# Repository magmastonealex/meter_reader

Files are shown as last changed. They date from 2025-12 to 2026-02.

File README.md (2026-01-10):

meter_reader
====

This is an open-hardware design for a magnetic gas / water meter "reader" or "snooper". It contains a magnetometer and microcontroller, and can measure the rotations of a water meter or oscillations of the bellows in a gas meter to fairly accurately track consumption of both natural gas and water.

The device communicates externally using CAN, accepting configuration and reporting sensor values.

Schematics and PCB design are in the root of this repository. I have built a few devices, but would not consider the hardware to be "fully qualified" yet - I still need to do some transient testing and measure power supplies and signal integrity. I'd also still like to find a more available magnetometer - MLX3094RLD is _barely_ available and a bit annoying to solder.

Firmware in `firmware/` is Rust code targetting the MSPM0G3107 on the board. I _think_ this is the first working example of MSPM0 CAN access in Rust on the internet :) It requires modifications to the mspm0-data crate which I have in a branch here: https://github.com/magmastonealex/mspm0-data - there is an open PR upstream where smarter people than I are figuring out a better way to do this.

The firmware right now is just bringing up various peripherals to prove they work - the code is very, very ugly, requiring a lot of cleanup, and doesn't really "do" anything yet.

More to come, including a blog post detailing assembly, development, and setup

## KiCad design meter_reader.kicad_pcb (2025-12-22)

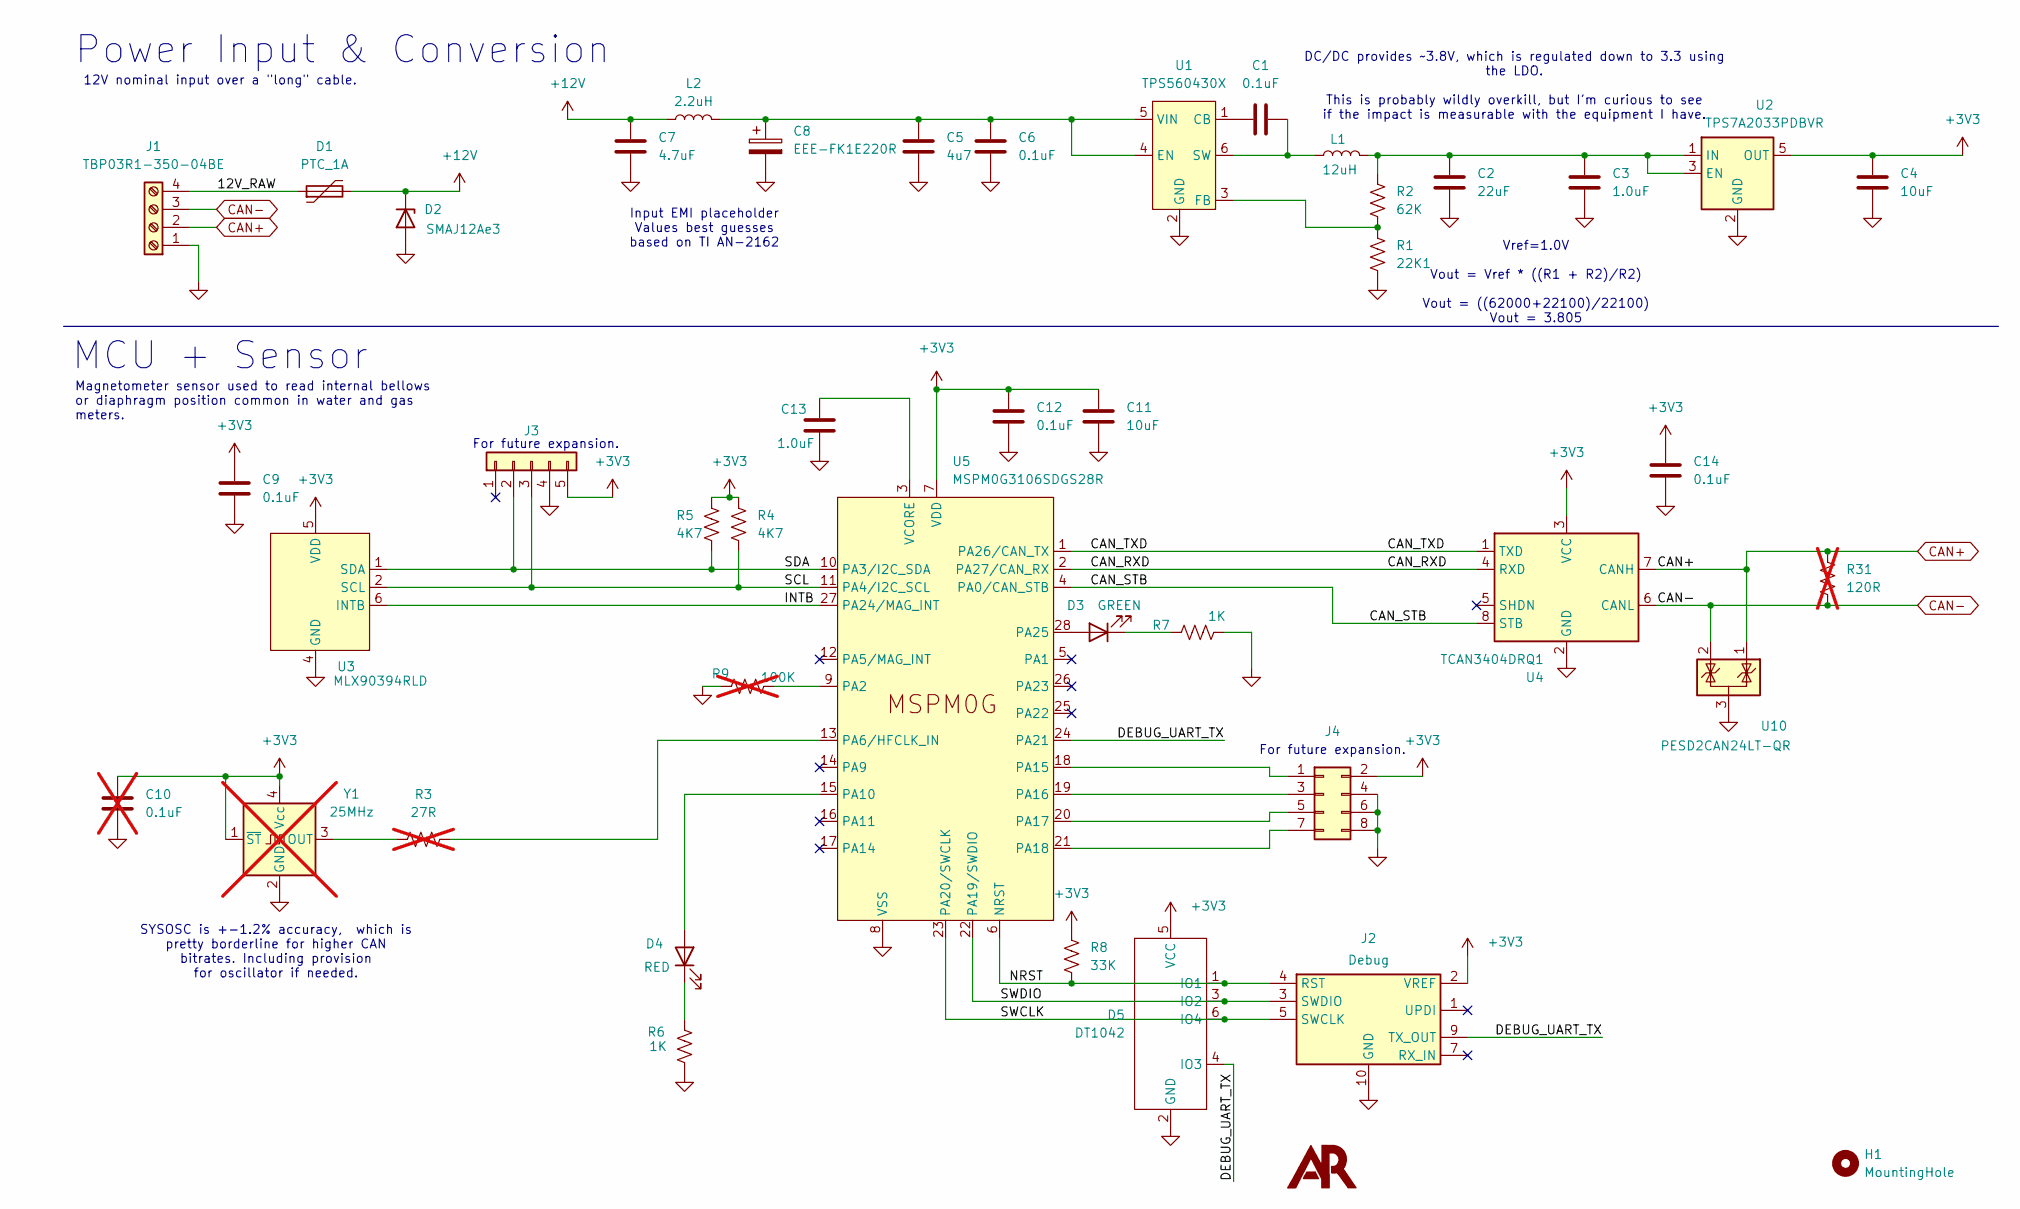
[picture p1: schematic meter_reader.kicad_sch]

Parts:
C1, C9: 0.1uF; C_0402_1005Metric
C2: 22uF; C_0805_2012Metric_Pad1.18x1.45mm_HandSolder
C3, C13: 1.0uF; C_0805_2012Metric_Pad1.18x1.45mm_HandSolder
C4, C11: 10uF; C_0805_2012Metric_Pad1.18x1.45mm_HandSolder
C5: 4u7; C_1206_3216Metric
C6, C12, C14: 0.1uF; C_0805_2012Metric_Pad1.18x1.45mm_HandSolder
C7: 4.7uF; C_1206_3216Metric
C8: EEE-FK1E220R; CP_Elec_5x5.8
C10: 0.1uF; C_0805_2012Metric_Pad1.18x1.45mm_HandSolder; not fitted
D1: PTC_1A; Fuse_1812
D2: SMAJ12Ae3; D_SMA
D3: GREEN; LED_0805_2012Metric_Pad1.15x1.40mm_HandSolder
D4: RED; LED_0805_2012Metric_Pad1.15x1.40mm_HandSolder
D5: DT1042; SOT-26
H1: MountingHole; MountingHole_2.2mm_M2
J1: TBP03R1-350-04BE; SameSky_TPB03R1-350-04BE
J2: Debug; Tag-Connect_TC2050-IDC-NL_2x05_P1.27mm_Vertical
J3: EXPAND; PinHeader_1x05_P2.54mm_Vertical
J4: Conn_02x04_Odd_Even; PinHeader_2x04_P2.54mm_Vertical
L1: 12uH; Bourns_SRR6038
L2: 2.2uH; L_1008_2520Metric
R1: 22K1; R_0805_2012Metric_Pad1.20x1.40mm_HandSolder
R2: 62K; R_0805_2012Metric_Pad1.20x1.40mm_HandSolder
R3: 27R; R_0603_1608Metric_Pad0.98x0.95mm_HandSolder; not fitted
R4, R5: 4K7; R_0805_2012Metric_Pad1.20x1.40mm_HandSolder
R6, R7: 1K; R_0805_2012Metric_Pad1.20x1.40mm_HandSolder
R8: 33K; R_0805_2012Metric_Pad1.20x1.40mm_HandSolder
R9: 100K; R_0805_2012Metric_Pad1.20x1.40mm_HandSolder; not fitted
R31: 120R; R_1210_3225Metric; not fitted
REF1: Touchmark_small
U1: TPS560430X; SOT-23-6
U2: TPS7A2033PDBVR; SOT-23-5
U3: MLX90394RLD; UTDFN-6-1EP_2x1.5mm_P0.5mm_EP0.8x0.8mm
U4: TCAN3404DRQ1; SOIC-8_3.9x4.9mm_P1.27mm
U5: MSPM0G3106SDGS28R; VSSOP-28_3x7.1mm_P0.5mm
U10: PESD2CAN24LT-QR; SOT-23
Y1: 25MHz; Oscillator_SMD_SeikoEpson_SG210-4Pin_2.5x2.0mm; not fitted

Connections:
+3V3: C4.1, C9.2, C10.1, C11.1, C12.1, C14.1, D5.5 (VCC), J2.2 (VREF), J3.5, J4.2, R4.2, R5.2, R8.1, U2.5 (OUT), U3.5 (VDD), U4.3 (VCC), U5.7 (VDD), Y1.1 (~ST), Y1.4 (Vcc)
+12V: C7.1, D1.2, D2.1 (K), L2.1
/12V_RAW: D1.1, J1.4
/CAN_RXD: U4.4 (RXD), U5.2 (PA27/CAN_RX)
/CAN_STB: U4.8 (STB), U5.4 (PA0/CAN_STB)
/CAN_TXD: U4.1 (TXD), U5.1 (PA26/CAN_TX)
/DEBUG_UART_TX: D5.4 (IO3), J2.9 (TX_OUT), U5.24 (PA21)
/INTB: U3.6 (INTB), U5.27 (PA24/MAG_INT)
/NRST: D5.1 (IO1), J2.4 (RST), R8.2, U5.6 (NRST)
/SCL: J3.3, R4.1, U3.2 (SCL), U5.11 (PA4/I2C_SCL)
/SDA: J3.2, R5.1, U3.1 (SDA), U5.10 (PA3/I2C_SDA)
/SWCLK: D5.6 (IO4), J2.5 (SWCLK), U5.23 (PA20/SWCLK)
/SWDIO: D5.3 (IO2), J2.3 (SWDIO), U5.22 (PA19/SWDIO)
CAN+: J1.2, R31.1, U4.7 (CANH), U10.1 (K)
CAN-: J1.3, R31.2, U4.6 (CANL), U10.2 (K)
GND: C2.2, C3.2, C4.2, C5.2, C6.2, C7.2, C8.2, C9.1, C10.2, C11.2, C12.2, C13.2, C14.2, D2.2 (A), D5.2 (GND), J1.1, J2.6 (GND), J2.8 (GND), J2.10 (GND), J3.4, J4.4, J4.6, J4.8, R1.2, R6.2, R7.2, R9.1, U1.2 (GND), U2.2 (GND), U3.3 (GND), U3.4 (GND), U4.2 (GND), U5.8 (VSS), U10.3 (A), Y1.2 (GND)
unnamed: D3.2 (A), U5.28 (PA25)
unnamed: D3.1 (K), R7.1
unnamed: D4.2 (A), U5.15 (PA10)
unnamed: D4.1 (K), R6.1
unnamed: J4.1, U5.18 (PA15)
unnamed: J4.3, U5.19 (PA16)
unnamed: J4.5, U5.20 (PA17)
unnamed: J4.7, U5.21 (PA18)
unnamed: C1.1, U1.1 (CB)
unnamed: C5.1, C6.1, C8.1, L2.2, U1.4 (EN), U1.5 (VIN)
unnamed: R1.1, R2.2, U1.3 (FB)
unnamed: C1.2, L1.1, U1.6 (SW)
unnamed: C2.1, C3.1, L1.2, R2.1, U2.1 (IN), U2.3 (EN)
unnamed: R9.2, U5.9 (PA2)
unnamed: R3.1, U5.13 (PA6/HFCLK_IN)
unnamed: C13.1, U5.3 (VCORE)
unnamed: R3.2, Y1.3 (OUT)

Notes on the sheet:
SYSOSC is +-1.2% accuracy, which is pretty borderline for higher CAN bitrates. Including provision for oscillator if needed.
12V nominal input over a "long" cable.
DC/DC provides ~3.8V, which is regulated down to 3.3 using the LDO. This is probably wildly overkill, but I'm curious to see if the impact is measurable with the equipment I have.
Power Input & Conversion
Input EMI placeholder Values best guesses based on TI AN-2162
For future expansion.
Magnetometer sensor used to read internal bellows or diaphragm position common in water and gas meters.
Vref=1.0V Vout = Vref * ((R1 + R2)/R2) Vout = ((62000+22100)/22100) Vout = 3.805
MCU + Sensor

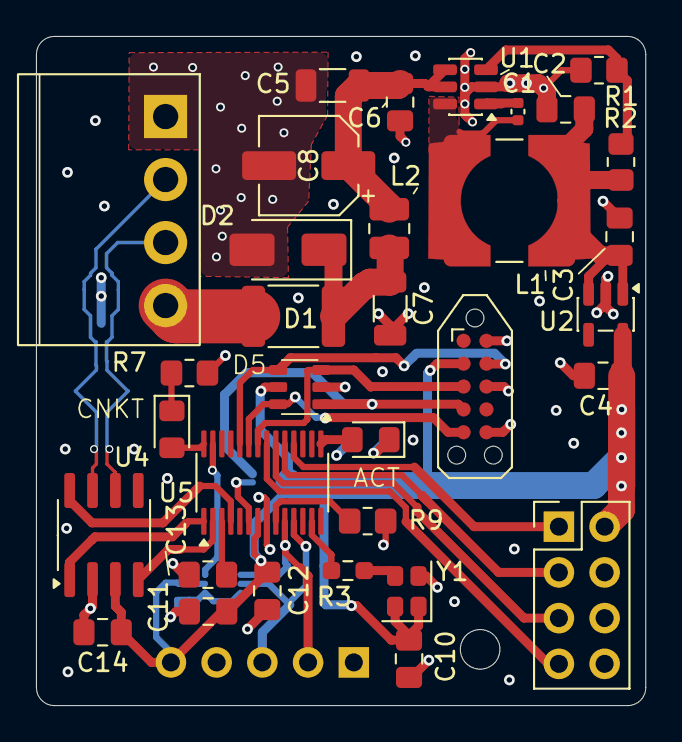
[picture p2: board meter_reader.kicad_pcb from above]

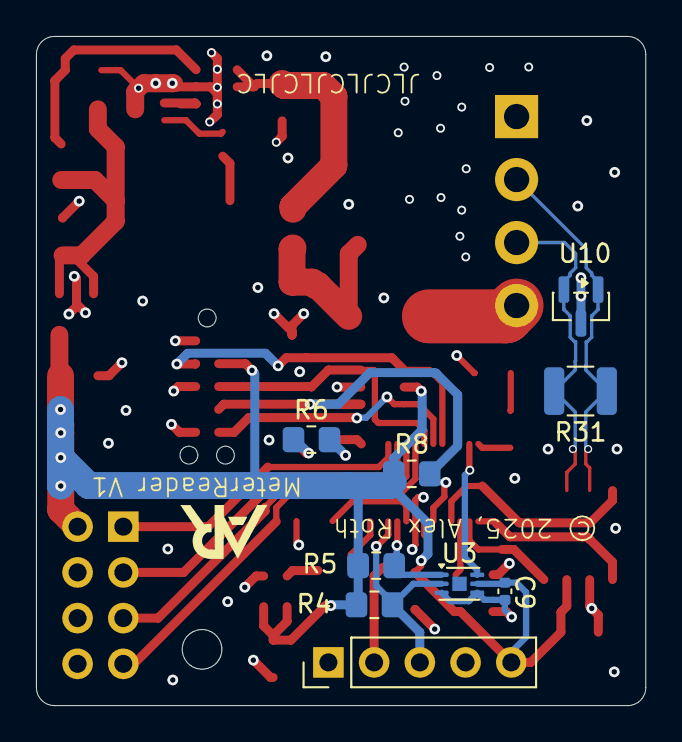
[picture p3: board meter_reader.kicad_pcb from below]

Board: 4 copper layers, 33.8 x 37.2 mm, 44 parts (10 on the bottom side), 33 nets.

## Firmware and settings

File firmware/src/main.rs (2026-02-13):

#![no_main]
#![no_std]

mod mlx;

use core::fmt;
use core::panic::PanicInfo;
use core::sync::atomic::{AtomicBool, Ordering, compiler_fence};

use embassy_futures::select::{Either, select};
use embassy_mspm0::can::CanTimings;
use embassy_mspm0::can::frame::MCanFrame;
use embassy_mspm0::gpio::Input;
use embassy_mspm0::mode::Async;
use embassy_mspm0::gpio::Output;
use embassy_mspm0::pac::sysctl::vals::ResetcmdKey;
use embassy_sync::lazy_lock::LazyLock;

use embassy_mspm0::wwdt::{self, Watchdog};
use embassy_mspm0::{bind_interrupts, can};
use embassy_mspm0::i2c::{self, I2c as PeriphI2c};
use embassy_mspm0::peripherals::{I2C1, CANFD0};

use embassy_mspm0::uart::UartTx;

use embassy_sync::blocking_mutex::raw::ThreadModeRawMutex;
use embedded_hal_async::i2c::I2c;
use embedded_io_async::Write;

use embassy_sync::channel::{Channel, DynamicReceiver, DynamicSender};
use embassy_time::{Duration, Instant, Timer};

use embassy_executor::Spawner;

use embedded_storage_async::nor_flash::{NorFlash, ReadNorFlash};
use mlx::Mlx90394;

use embedded_can::{ExtendedId, Frame, Id, StandardId};

use defmt::{error, info, warn};

mod flashdriver;
mod configutils;

use defmt_rtt as _;

mod pulse_counter;

//use panic_probe as _;
use sequential_storage::cache::NoCache;
use sequential_storage::map::{MapConfig, MapStorage};

use crate::configutils::MagnetometerConfig;
use crate::mlx::MlxError;
use crate::pulse_counter::PulseCounter;

bind_interrupts!(struct Irqs {
    I2C1 => i2c::InterruptHandler<I2C1>;
    CANFD0 => can::InterruptHandler<CANFD0>;
});


fn uart_ll_write(buffer: &[u8]) {
    for &b in buffer {
        while ! embassy_mspm0::pac::UART2.stat().read().txfe() {}
        compiler_fence(Ordering::Release);
        embassy_mspm0::pac::UART2.txdata().write(|w| {
            w.set_data(b);
        });
    }

}

#[allow(dead_code)]
#[derive(Debug, defmt::Format, PartialEq, Eq)]
#[repr(u8)]
enum MessageType {
    /// A notification that a device reset for some reason.
    DeviceReset = 0x0F,

    /// The device has encountered a fatal error.
    DeviceError = 0x00,

    /// The device has taken your request into account.
    DeviceAck = 0x01,
    /// The device wasn't able to apply a config or debug mode that was requested.
    DeviceWarning = 0x02,
    
    /// A notification that a device is still alive.
    DeviceHello = 0x10,

    /// Sensor reading from this device?
    DeviceRawData = 0x11,
    
    /// Sensor reading from this device?
    DeviceMeterTicks = 0x12,

    /// If the device has encountered a pulse (indicating some flow) in the past minute.
    DeviceMeterActive = 0x13,

    /// Request device enter debug mode to dump data at 5hz.
    DeviceDebugMode = 0x14,

    DeviceReconfigure = 0x15,
    DeviceGetCurrentConfig = 0x18,
    DeviceGetCurrentConfigResp=0x19,

    DeviceSetStartPoint = 0x16,
    DevicePleaseReset = 0x17,
    DeviceCANStatus = 0x1a,
}

impl TryFrom<u8> for MessageType {
    type Error = ();
    fn try_from(value: u8) -> Result<Self, Self::Error> {
        info!("checking against: {:02x}", value);
        match value {
            0x0F => Ok(MessageType::DeviceReset),
            0x00 => Ok(MessageType::DeviceError),
            0x10 => Ok(MessageType::DeviceHello),
            0x11 => Ok(MessageType::DeviceRawData),
            0x12 => Ok(MessageType::DeviceMeterTicks),
            0x14 => Ok(MessageType::DeviceDebugMode),
            0x1a => Ok(MessageType::DeviceCANStatus),
            0x15 => Ok(MessageType::DeviceReconfigure),
            0x16 => Ok(MessageType::DeviceSetStartPoint),
            0x17 => Ok(MessageType::DevicePleaseReset),
            0x18 => Ok(MessageType::DeviceGetCurrentConfig),
            0x19 => Ok(MessageType::DeviceGetCurrentConfigResp),
            _ => Err(())
        }
    }
}

static DEVICE_ADDR_SUFFIX: LazyLock<u32> = LazyLock::new(|| {
    // addr prefix is the traceid masked to a 21 bit value, leaving the upper 8 bits of a CAN address free.
    // This allows arbitration to work based on message type, but also ensures the values are unique.
    let traceid: u32 = unsafe{ core::ptr::read_volatile((0x41C4_0000) as *const u32) };

    // TRM says that TRACEID is unique per part shipped,
    // though https://e2e.ti.com/support/microcontrollers/arm-based-microcontrollers-group/arm-based-microcontrollers/f/arm-based-microcontrollers-forum/1302805/lp-mspm0l1306-iden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
    // casts some doubt on that. I suspect traceid is like a serial number but only within the actual unique dies, so would need to be qualified by deviceid/userid in more hardened situations
    info!("traceid: {:08x}", traceid);
    traceid & (0xFFFF)
});

fn get_can_id(device_suffix: u32, message_type: MessageType) -> ExtendedId {
    let typ: u8 = message_type as u8;
    //0017edf1
    //1FFFFFFF
    let extid = (device_suffix & 0xFFFF) | ((typ as u32) << 16);

    ExtendedId::new(extid).unwrap()
}

fn is_for_device(frame: &MCanFrame) -> bool {
    if let Id::Extended(e) = frame.id() {
        (e.as_raw() & 0xFFFF) == *DEVICE_ADDR_SUFFIX.get()
    } else {
        false
    }
}

fn get_message_type(frame: &MCanFrame) -> Option<MessageType> {
    if let Id::Extended(e) = frame.id() {
        info!("frame id for type: {:08x}", e.as_raw());
        match MessageType::try_from((e.as_raw() >> 16) as u8) {
            Ok(typ) => {
                Some(typ)
            },
            Err(_) => {
                None
            }
        }

    } else {
        None
    }
}

// This panic handler dumps stuff to UART.
// Note this is not particularly code-size efficient as it brings in a lot of formatting garbage just for panics (>> 10KB).
// This is fine for development where panics are possible, but should really be disabled in production releases.
#[panic_handler]
fn panic(info: &PanicInfo) -> ! {
    static PANICKED: AtomicBool = AtomicBool::new(false);

    cortex_m::interrupt::disable();
    
    // Guard against infinite recursion, just in case.
    if !PANICKED.load(Ordering::Relaxed) {
        PANICKED.store(true, Ordering::Relaxed);

        let msg = info.message().as_str().unwrap_or("No panic message!");

        uart_ll_write("******Panicked!*********\r\n".as_bytes());
        uart_ll_write("Message: ".as_bytes());
        uart_ll_write(msg.as_bytes());
        uart_ll_write("\r\nLocation: ".as_bytes());
        if let Some(l) = info.location() {
            uart_ll_write("file: ".as_bytes());
            uart_ll_write(l.file().as_bytes());
        } else {
            uart_ll_write("No location info.\r\n".as_bytes());
        }

    }

    loop {
        // hope you remembered to set a watchdog.
        embassy_mspm0::pac::SYSCTL.resetlevel().write(|w| {
            w.set_level(embassy_mspm0::pac::sysctl::vals::ResetlevelLevel::POR);
        });
        embassy_mspm0::pac::SYSCTL.resetcmd().write(|w| {
            w.set_key(ResetcmdKey::KEY);
            w.set_go(true);
        });
    }
}

/// Hardfault handler.
///
/// Terminates the application and makes a semihosting-capable debug tool exit
/// with an error. This seems better than the default, which is to spin in a
/// loop.
#[cortex_m_rt::exception]
unsafe fn HardFault(_frame: &cortex_m_rt::ExceptionFrame) -> ! {
    panic!("Got a HardFault");
}

static OUTBOUND: Channel<ThreadModeRawMutex, MCanFrame, 10> = Channel::new();

static IS_METER_ACTIVE: AtomicBool = AtomicBool::new(false);

#[embassy_executor::task]
async fn periodic_hello(outgoing: DynamicSender<'static, MCanFrame>) {
    let id = get_can_id(*DEVICE_ADDR_SUFFIX.get(), MessageType::DeviceHello);
    loop {
        let mut data = [0x00u8; 2];
        if IS_METER_ACTIVE.load(Ordering::Relaxed) {
            data[1] = 0x01;
        }
        Timer::after_secs(5).await;
        let frame = MCanFrame::new(Id::Extended(id), &data).unwrap();
        match outgoing.try_send(frame) {
            Ok(_) => {},
            Err(_) => {
                warn!("failed to send hello - queue full?");
            }
        }
    }
}

#[embassy_executor::task]
async fn transmitter_mux(mut tx: can::CanTx<Async>, incoming: DynamicReceiver<'static, MCanFrame>) {
    loop {
        let frame = incoming.receive().await;
        tx.enqueue_frame(&frame).await.expect("no buserror possible");
    }
}

#[embassy_executor::task]
async fn receiver(mut rx: can::CanRx<Async>, outgoing: DynamicSender<'static, MCanFrame>) {
    loop {
        let mut frame = rx.get_frame().await.expect("no buserror possible right now");
        info!("Received frame: {}", frame);
        frame.set_id(Id::Standard(StandardId::new(0x0ab).unwrap()));
        info!("Sending reply... {}", frame);
        outgoing.send(frame).await;    
    }
}

#[embassy_executor::task]
async fn can_maintainer(mut status: can::CanStatus<'static>, outgoing: DynamicSender<'static, MCanFrame>) {
    let mut interval = 0;
    loop {
        Timer::after_secs(3).await;

        let errors = status.get_error_counters();

        info!("CAN error counters: {:?}", errors);

        if errors.bus_off {
            info!("Starting bus-off recovery");
            match status.recover() {
                Ok(_) => {
                    info!("Bus-off recovery completed.");
                }
                Err(e) => {
                    warn!("Bus-off recovery failed: {}", e);
                }
            }
        } else {
            interval += 1;
            if interval > 5 {
                interval = 0;
                try_send_canstats(errors.tec, errors.rec, &outgoing);
            }
        }
    }
}


async fn send_error_and_panic(reason: u8, outgoing: &DynamicSender<'_, MCanFrame>) -> ! {
    let frame = MCanFrame::new(Id::Extended(get_can_id(*DEVICE_ADDR_SUFFIX.get(), MessageType::DeviceError)), &[0x00, reason]).unwrap();
    match outgoing.try_send(frame) {
        Ok(_) => {},
        Err(_) => {
            panic!("init panic: {} - failed send", reason);
        }
    }
    Timer::after_millis(100).await;
    panic!("init panic: {}", reason);
}

fn try_send_warning(reason: u8, outgoing: &DynamicSender<'_, MCanFrame>) {
    let frame = MCanFrame::new(Id::Extended(get_can_id(*DEVICE_ADDR_SUFFIX.get(), MessageType::DeviceWarning)), &[0x00, reason]).unwrap();
    match outgoing.try_send(frame) {
        Ok(_) => {},
        Err(_) => {
            warn!("failed to send warning");
        }
    }
}

fn try_send_ack(reason: u8, outgoing: &DynamicSender<'_, MCanFrame>) {
    let frame = MCanFrame::new(Id::Extended(get_can_id(*DEVICE_ADDR_SUFFIX.get(), MessageType::DeviceAck)), &[0x00, reason]).unwrap();
    match outgoing.try_send(frame) {
        Ok(_) => {},
        Err(_) => {
            warn!("failed to send ack");
        }
    }
}

fn try_send_count(ticks: u32, outgoing: &DynamicSender<'_, MCanFrame>) {
    let mut dataframe = [0x00u8; 5];

    dataframe[1..5].copy_from_slice(&ticks.to_be_bytes());

    let frame = MCanFrame::new(Id::Extended(get_can_id(*DEVICE_ADDR_SUFFIX.get(), MessageType::DeviceMeterTicks)), &dataframe).unwrap();
    match outgoing.try_send(frame) {
        Ok(_) => {},
        Err(_) => {
            warn!("failed to send count");
        }
    }
}

fn try_send_canstats(tec: u8, rec: u8, outgoing: &DynamicSender<'_, MCanFrame>) {
    let mut dataframe = [0x00u8; 3];

    dataframe[1] = tec;
    dataframe[2] = rec;

    let frame = MCanFrame::new(Id::Extended(get_can_id(*DEVICE_ADDR_SUFFIX.get(), MessageType::DeviceCANStatus)), &dataframe).unwrap();
    match outgoing.try_send(frame) {
        Ok(_) => {},
        Err(_) => {
            warn!("failed to send count");
        }
    }
}

async fn wait_for_drdy(mag: &mut Mlx90394<'_, PeriphI2c<'_, Async>>) {
    loop {
        match mag.data_ready().await {
            Ok(v) => {
                if v {
                    return;
                }
            },
            Err(e) => {
                warn!("Got MLX error: {}", e);
                Timer::after_millis(100).await;
            }
        }

    }
}

#[embassy_executor::main]
async fn main(spawner: Spawner) -> ! {
    let periph = embassy_mspm0::init(Default::default());
    let mut led_output = Output::new(periph.PA25, embassy_mspm0::gpio::Level::Low);
    let mut led_output_2 = Output::new(periph.PA10, embassy_mspm0::gpio::Level::High);
    let mut mlx_drdy = Input::new(periph.PA24, embassy_mspm0::gpio::Pull::Up);
    let canstb = Output::new(periph.PA0, embassy_mspm0::gpio::Level::Low);

    // Hack: Set up HFXT with the 25MHz oscillator
    // We'll use this for clocking the CAN peripheral
    // PA6 - PINCM11. Pin function 6 is HFCLK_IN.
    embassy_mspm0::pac::IOMUX.pincm(10).modify(|w| {
        w.set_pf(6);
        w.set_inena(true);
        w.set_pc(true);
    });
    embassy_mspm0::pac::SYSCTL.hsclken().modify(|w| {
        w.set_useexthfclk(true);
    });

    let mut cnt = 0;
    while !embassy_mspm0::pac::SYSCTL.clkstatus().read().hfclkgood() {
        if cnt > 100000 {
            panic!("no hfclk");
        }
        cnt += 1;
        cortex_m::asm::delay(100);
    }
    
    // Configure UART first - we will use it in our panic handler.
    let mut config = embassy_mspm0::uart::Config::default();
    config.baudrate = 115200;
    let mut uart = UartTx::new_blocking(periph.UART2, periph.PA21, config).unwrap();

    uart.blocking_write("hello\r\n".as_bytes()).unwrap();


    let mut mcan_config = can::Config::default();
    mcan_config.timing = CanTimings { brp: 1, sjw: 30, ntseg1: 219, ntseg2: 30 };
    let candriver = can::Can::new_async(periph.CANFD0, periph.PA27, periph.PA26, Irqs, mcan_config).unwrap();
    let (tx, mut rx, status) = candriver.split();

    spawner.spawn(transmitter_mux(tx, OUTBOUND.dyn_receiver()).unwrap());
    spawner.spawn(periodic_hello(OUTBOUND.dyn_sender()).unwrap());
    spawner.spawn(can_maintainer(status, OUTBOUND.dyn_sender()).unwrap());

    let outgoing = OUTBOUND.dyn_sender();

    // Send our "reset hello" indicating that we reset and why.
    let rstcause_raw = (embassy_mspm0::pac::SYSCTL.rstcause().read().0 & 0x0F) as u8;
    let frame = MCanFrame::new(Id::Extended(get_can_id(*DEVICE_ADDR_SUFFIX.get(), MessageType::DeviceReset)), &[0x00, rstcause_raw]).unwrap();
    outgoing.send(frame).await;

    // Now that we have sent our reset cause,
    // we can enable resetting upon a variety of non-recoverable faults...
    embassy_mspm0::pac::SYSCTL.systemcfg().write(|w| {
        w.set_flasheccrstdis(false);
        w.set_wwdtlp0rstdis(false);
        w.set_wwdtlp1rstdis(false);
    });

    // Enable our watchdog before we start initializing "risky" peripherals.
    let mut watchdog_cfg = wwdt::Config::default();
    watchdog_cfg.closed_window = wwdt::ClosedWindowPercentage::Zero;
    watchdog_cfg.timeout = wwdt::Timeout::Sec4;
    let mut watchdog = Watchdog::new(periph.WWDT0, watchdog_cfg);
    watchdog.pet();

    // Initialize i2c.
    let mut cfg = i2c::Config::default();
    cfg.bus_speed = i2c::BusSpeed::FastMode;
    let mut i2cinter = match i2c::I2c::new_async(periph.I2C1, periph.PA4, periph.PA3, Irqs, cfg) {
        Ok(drv) => drv,
        Err(e) => {
            error!("i2c config error: {}", e);

           send_error_and_panic(0x01, &outgoing).await;
        }
    };

    let controller = flashdriver::FlashController::new(flashdriver::take().unwrap(), 0x0001_E000, 0x0002_0000);
    let mut storage: MapStorage<u8, flashdriver::FlashController, NoCache> = MapStorage::<u8, _, _>::new(controller, const { MapConfig::new(0x0001E000..0x00020000) }, NoCache::new());

    //storage.store_item::<[u8; 3]>(&mut tmpbuf, &0x01, &[0x05, 0x10, 0xAB]).await.unwrap();
    let meter_ticks: u32 = configutils::get_value_or(&mut storage, configutils::ConfigKey::MeterTicks, 0u32).await;
    info!("Loaded meter ticks: {}", meter_ticks);
    let mut mag_config: MagnetometerConfig = configutils::get_bitfield_or(&mut storage, configutils::ConfigKey::MagnetometerConfig, MagnetometerConfig::default()).await;

    let mut pulse_counter = PulseCounter::new(mag_config.rising_val(), mag_config.rising_delta(), meter_ticks);

    try_send_count(pulse_counter.count(), &outgoing);

    let starting_config: mlx::Config = match (&mag_config).try_into() {
        Ok(cfg) => cfg,
        Err(_) => {
            error!("Config in flash is bad for mlx (flash corrupted!?)");
            send_error_and_panic(0x02, &outgoing).await;
        }
    };

    info!("Got starting MLX config: {}", mag_config);
    info!("clk status? {:x}", embassy_mspm0::pac::SYSCTL.clkstatus().read().hfclkgood());

    let mut attempt = 0;
    let mut mag = loop {
        let addr = if attempt % 2 == 0 {0x10} else {0x60};

        match select(
            Mlx90394::new_init(&mut i2cinter, addr, &starting_config),
            Timer::after_millis(250)
        ).await {
            Either::First(Ok(mlx)) => {
                break mlx
            }
            Either::First(Err(_)) => {
                attempt += 1;
                if attempt > 10 {
                    error!("Failed to initialize after multiple attempts - giving up");
                    send_error_and_panic(0x03, &outgoing).await;
                }
                info!("Failed. Trying again... {}", addr);
                watchdog.pet();
                Timer::after_millis(100).await;
            }
            Either::Second(_) => {
                error!("Detected bus latchup - not handling this right now.");
                uart.blocking_write("latchup\r\n".as_bytes()).unwrap();
                send_error_and_panic(0x04, &outgoing).await;
            }
        }
    };
    info!("Initialized MLX");
    watchdog.pet();

    // "debug mode" is triggered through a received CAN frame
    // and causes the device to report the values of every reading,
    // used for initial calibration and other debugging.
    let mut is_debug_mode = false;

    let mut last_pulse = Instant::now();
    let mut last_update = Instant::now();

    loop {
        //if mlx.data_ready().await.unwrap() {
            match select(rx.get_frame(), mlx_drdy.wait_for_low()).await {
                Either::First(Ok(frame)) if is_for_device(&frame) => {
                    match get_message_type(&frame) {
                        Some(MessageType::DeviceDebugMode) => {
                            if frame.data().len() >= 1 && frame.data()[0] == 0x01 {
                                is_debug_mode = true;
                                // reconfigure the magnetometer for debug mode - all axes, sensitivity depends on message, 5 hz.
                                let mut cfg = const {mlx::Config::new(0x02).unwrap()}; // 5 hz;
                                cfg.en_x = true;
                                cfg.en_y = true;
                                cfg.en_z = true;

                                if frame.data().len() > 1 && frame.data()[1] == 0x01 {
                                    cfg.high_sensitivity = true;
                                } else {
                                    cfg.high_sensitivity = false;
                                }
                                
                                if let Err(e) = mag.reconfigure(&cfg).await {
                                    warn!("Failed to reconfigure MLX... {}", e);
                                    try_send_warning(0x01, &outgoing);
                                } else {
                                    try_send_ack(MessageType::DeviceDebugMode as u8, &outgoing);
                                }
                            } else {
                                is_debug_mode = false;
                                match (&mag_config).try_into() {
                                    Ok(cfg) => {
                                        if let Err(e) = mag.reconfigure(&cfg).await {
                                            warn!("Failed to reconfigure MLX... {}", e);
                                            try_send_warning(0x10, &outgoing);
                                        } else {
                                            try_send_ack(MessageType::DeviceDebugMode as u8, &outgoing);
                                        }
                                    },
                                    Err(_) => {
                                        warn!("invalid mlx config - this is super bad!");
                                        try_send_warning(0x11, &outgoing);
                                    }
                                }
                            }
                        },
                        Some(MessageType::DeviceSetStartPoint) => {
                            if frame.data().len() == 4 {
                                let meter_ticks = u32::from_be_bytes(frame.data().try_into().unwrap());

                                pulse_counter.set_count(meter_ticks);
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

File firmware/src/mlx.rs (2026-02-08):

#![allow(dead_code)]
use defmt::info;
use embassy_time::Timer;
use embedded_hal_async::i2c::{I2c};

#[derive(Debug, PartialEq, Eq, defmt::Format)]
pub struct MagReadings {
    pub x: i16,
    pub y: i16,
    pub z: i16,

    pub x_sat: bool,
    pub y_sat: bool,
    pub z_sat: bool,
    pub overflowed: bool
}

impl MagReadings {
    fn from_raw(main_data: [u8; 7]) -> Self {
        let mut data = MagReadings{
            x: i16::from_le_bytes(main_data[0..2].try_into().unwrap()),
            y: i16::from_le_bytes(main_data[2..4].try_into().unwrap()),
            z: i16::from_le_bytes(main_data[4..6].try_into().unwrap()),

            x_sat: false,
            y_sat: false,
            z_sat: false,
            overflowed: false
        };

        if (main_data[6] & 0x01) != 0 {
            data.x_sat = true;
        }
        if (main_data[6] & 0x02) != 0 {
            data.y_sat = true;
        }
        if (main_data[6] & 0x04) != 0 {
            data.y_sat = true;
        }
        if (main_data[6] & 0x08) != 0 {
            data.overflowed = true;
        }

        //defmt::info!("Readings X: {:016b} Y: {:b} Z: {:016b} D: {:08b}", data.x, data.y, data.z, main_data[6]);
        data
    }

    pub fn serialize(&self) -> [u8; 7] {
        let mut result = [0u8; 7];
        // X field (bytes 0-1)
        result[0..2].copy_from_slice(&self.x.to_be_bytes());

        // Y field (bytes 2-3)
        result[2..4].copy_from_slice(&self.y.to_be_bytes());

        // Z field (bytes 4-5)
        result[4..6].copy_from_slice(&self.z.to_be_bytes());

        // Status bitfield (byte 7)
        let mut status = 0u8;
        if self.x_sat { status |= 0x01; }
        if self.y_sat { status |= 0x02; }
        if self.z_sat { status |= 0x04; }
        if self.overflowed { status |= 0x08; }
        result[6] = status;

        result
    }
}

pub struct Mlx90394<'a, I2C> {
    i2c: &'a mut I2C,
    address: u8,
}

const REG_STAT1: u8 = 0x00;
const REG_X_LSB: u8 = 0x01;
const REG_X_MSB: u8 = 0x02;
const REG_Y_LSB: u8 = 0x03;
const REG_Y_MSB: u8 = 0x04;
const REG_Z_LSB: u8 = 0x05;
const REG_Z_MSB: u8 = 0x06;
const REG_STAT2: u8 = 0x07;
const REG_T_LSB: u8 = 0x08;
const REG_T_MSB: u8 = 0x09;
const REG_COMPANY_ID: u8 = 0x0A;
const REG_DEVICE_ID: u8 = 0x0B;
const REG_CTRL1: u8 = 0x0E;
const REG_CTRL2: u8 = 0x0F;
const REG_RESET: u8 = 0x11;
const REG_CTRL3: u8 = 0x14;
const REG_CTRL4: u8 = 0x15;
const REG_X_THR_LSB: u8 = 0x58;
const REG_X_THR_MSB: u8 = 0x59;
const REG_Y_THR_LSB: u8 = 0x5A;
const REG_Y_THR_MSB: u8 = 0x5B;
const REG_Z_THR_LSB: u8 = 0x5C;
const REG_Z_THR_MSB: u8 = 0x5D;

#[derive(Debug, Clone, Copy, PartialEq, Eq, defmt::Format)]
pub enum MlxError<E> {
    /// I2C communication error
    I2c(E),
    /// Magnetic sensor overflow on X axis
    OverflowX,
    /// Magnetic sensor overflow on Y axis
    OverflowY,
    /// Magnetic sensor overflow on Z axis
    OverflowZ,
    /// Invalid configuration
    InvalidConfig,
    /// Not the expected device.
    WrongDevice,
}
impl<E> From<E> for MlxError<E> {
    fn from(error: E) -> Self {
        MlxError::I2c(error)
    }
}

#[derive(Debug, Clone, Copy, PartialEq, Eq, defmt::Format)]
pub struct Config {
    pub high_sensitivity: bool,
    pub en_z: bool,
    pub en_x: bool,
    pub en_y: bool,
    rate: u8,
}

impl Config {
    pub const fn new(rate: u8) -> Option<Config> {
        if rate >= 15 || rate == 0 || rate == 1 || rate == 7 || rate == 8 || rate == 9 {
            return None;
        }

        Some(Config {
            high_sensitivity: false,
            en_x: true,
            en_y: true,
            en_z: true,
            rate: rate
        })
    }
}

impl<'a, I2C, E> Mlx90394<'a, I2C>
where
    I2C: I2c<Error = E>,
{   
    /// NOTE: a prior version of this driver accepted drdy input to await internally,
    /// but I don't think the mspm0 i2c driver handles a future being dropped due to a timeout very well.
    /// I want to be very careful in my "select" in the main loop so I only select on drdy or a CAN frame,
    /// and don't wind up interrupting an i2c transaction halfway through which would be... bad.
    pub async fn new_init(i2c: &'a mut I2C,address: u8, config: &Config) -> Result<Self, MlxError<E>> {
        let mut inst = Self {
            i2c,
            address
        };

        // Note: writing to the wrong sensor first causes misbehaviour. I think this might be an i2c driver issue, since
        // the bytes on the wire are "shifted" by one so to speak.
        // regardless, doing a read to detect devices instead of a write resolves it.
        let mut cidbuf: [u8; 2] = [0u8; 2];

        inst.read_registers_base(&mut cidbuf[0..1]).await?;

        inst.read_registers(REG_COMPANY_ID, &mut cidbuf).await?;

        if cidbuf[0] != 0x94 && cidbuf[1] != 0xAA {
            return Err(MlxError::WrongDevice)
        }

        inst.write_register(REG_RESET, 0x06).await?;
        
        // wait a bit of a while for it to come out of reset.
        Timer::after_millis(10).await;

        let stat1 = inst.read_register(REG_STAT1).await?;
        if stat1 & (1<<3) == 0 {
            // not reset?
            info!("not reset - something weird happened");
        }

        inst.reconfigure(config).await?;

        Ok(inst)
    }

    pub async fn reconfigure(&mut self, config: &Config) -> Result<(), MlxError<E>> {
        info!("Configuring MLX with: {}", config);
        // stop measurements.
        let ctrl1: u8 = 0; // disable everything.
        self.write_register(REG_CTRL1, ctrl1).await?;

        let mut ctrl2: u8  = 1 << 3; // Interrupt on INTB pin (will use for dready to avoid polling i2c.)
        if config.high_sensitivity {
            ctrl2 |= 1 << 7;  // CONFIG1 = 1 - configuration 2 for high sensitivity
        } else {
            ctrl2 |= 1 << 6; // CONFIG0 = 1 - configuration 1 for high range
        }

        self.write_register(REG_CTRL2, ctrl2).await?;

        let ctrl3:u8 = (1 << 7) | // enable oversampling for hall measurements
            (1 << 6) | // Enable oversampling for temperature measurements
            (6 << 3) | // Enable 4 filter taps for XY hall effect measurement - see https://github.com/zephyrproject-rtos/zephyr/blob/4f3478391a3c5e555dcd629f9e829378c17b0d62/drivers/sensor/melexis/mlx90394/mlx90394.c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 - this will take 490 us per axis.
            (6 << 0); // Enable 4 filter taps for temperature measurement.
        self.write_register(REG_CTRL3, ctrl3).await?;

        let ctrl4: u8 = (1 << 7) | // rsvd
            (0<<6) | // rsvd
            (1<<5) | // enable temp measurement
            (1<<4) | // rsvd
            (1<<3) | // drdy output on intb
            (6<<0); // 4 filter taps for Z hall effect measurement.

        self.write_register(REG_CTRL4, ctrl4).await?;
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

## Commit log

2025-12-17 Project start
    [meter_reader.kicad_pcb, meter_reader.kicad_sch]
2025-12-17 Schematic completed, starting on placement
    [meter_reader.kicad_pcb, meter_reader.kicad_sch]
2025-12-17 placement continues
    [meter_reader.kicad_pcb, meter_reader.kicad_sch]
2025-12-20 Add breakout for backup magnetometer, add IO pin breakout, finish placement
    [meter_reader.kicad_pcb, meter_reader.kicad_sch]
2025-12-21 Meter reader V1 (probably) ready for fabrication
    [meter_reader.kicad_pcb, meter_reader.kicad_sch]
2025-12-22 Tidy up before mfg release
    [meter_reader.kicad_pcb, meter_reader.kicad_sch]
2026-01-03 defmt and UART seem to be working as expected
2026-01-08 working on actual board
2026-01-09 CAN peripheral is initialized, but not 100% reliably. Need to figure out a proper reset path.
    [main.rs]
2026-01-09 Don't reset the CAN peripheral. This causes misbehaviour
    [main.rs]
2026-01-10 Add notes to schematic from bringup
    [meter_reader.kicad_sch]
2026-01-11 Finally figure out why MCAN doesn't initialize on all boots
    [main.rs]
2026-01-11 Start on somewhat reasonable driver for CAN
2026-01-16 Can send and receive frames again
2026-02-01 update with new async support from CAn driver
2026-02-01 magnetometer is working with a slightly crappy driver
2026-02-04 Minimal flash driver is working. Now to decide if we want to implement the embedded-storage traits or DIY a flash layer
2026-02-06 Finish flash driver, add sequential-storage, some minor magnetometer improvements
2026-02-06 MLX readings work - bug in i2c driver identified with lack of repeated starts
    [main.rs, mlx.rs]
2026-02-06 Have MLX driver take drdy pin, use it for triggering data retrieval.
2026-02-07 Fixup CAN addressing. It works!
    [main.rs, mlx.rs]
2026-02-08 Fix reset timing with mlx. Fix up some protocol typos in main
    [main.rs, mlx.rs]
2026-02-08 Work around broken i2c driver for nacked writes
    [main.rs, mlx.rs]

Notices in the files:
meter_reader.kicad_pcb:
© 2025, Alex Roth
